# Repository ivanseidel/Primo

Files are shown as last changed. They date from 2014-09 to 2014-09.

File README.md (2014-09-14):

Custom Primo Version
=====

New here? Go to the [Manual](https://github.com/ivanseidel/Primo/blob/master/Manual.pdf?raw=true).

Or [Download all files](https://github.com/ivanseidel/Primo/archive/master.zip).

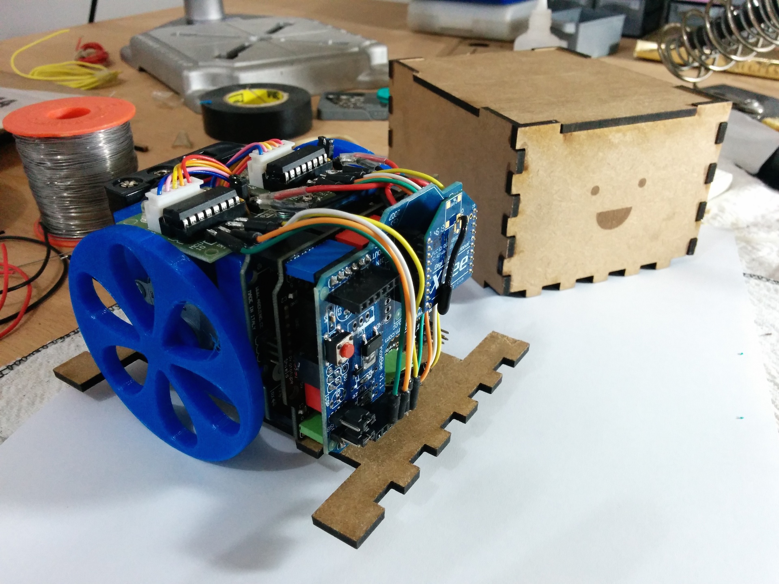
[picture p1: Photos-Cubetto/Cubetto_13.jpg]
Cubetto

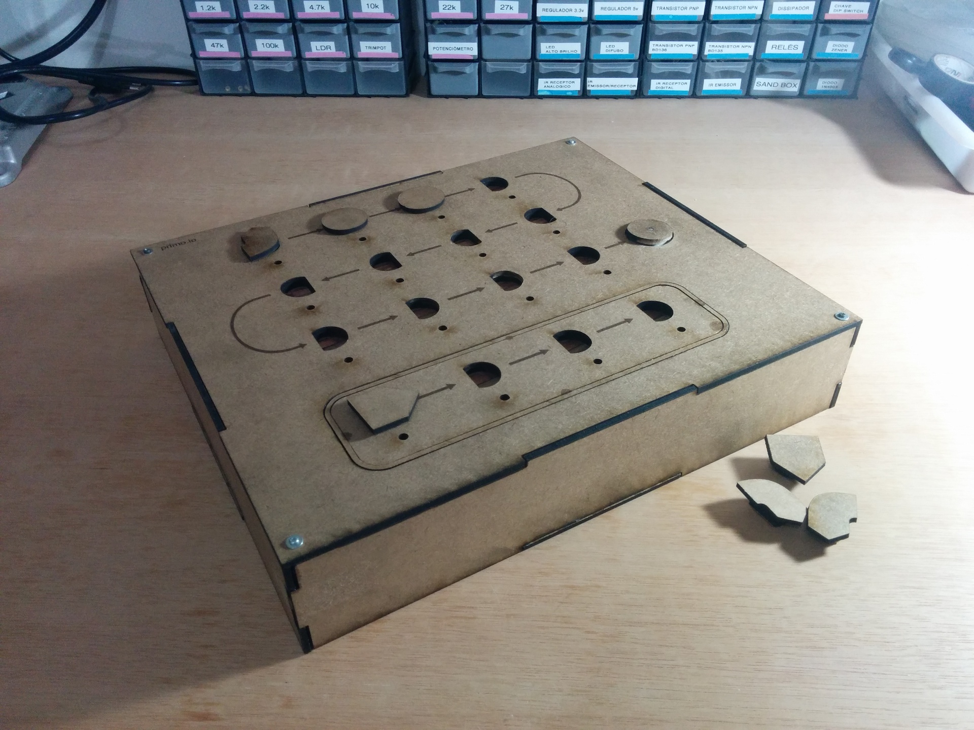
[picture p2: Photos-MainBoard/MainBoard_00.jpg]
Main Board


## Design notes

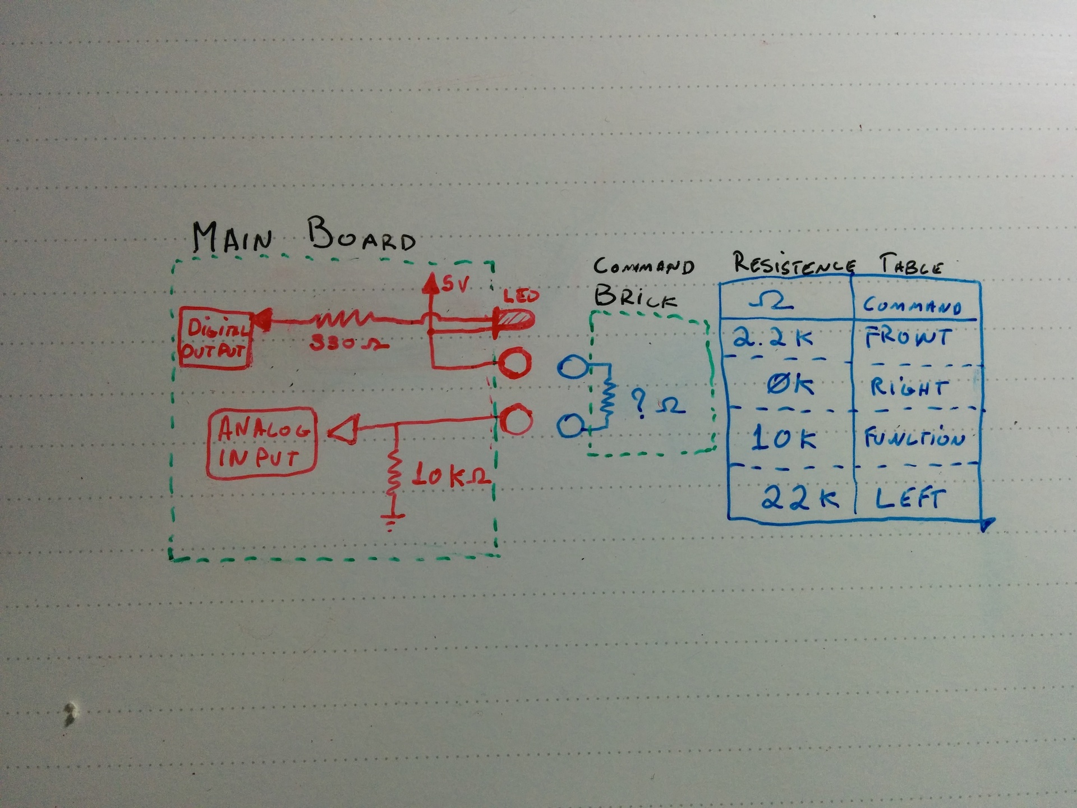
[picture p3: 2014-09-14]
Photos-MainBoard/Schematic_unit.jpg

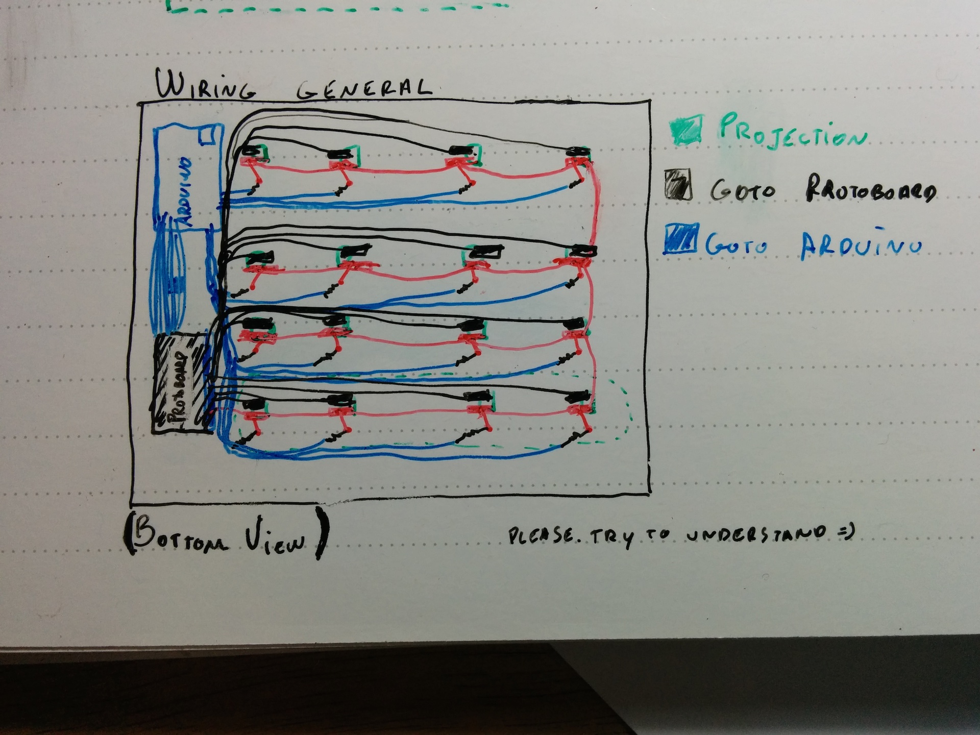
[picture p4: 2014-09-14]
Photos-MainBoard/Schematic_overview.jpg

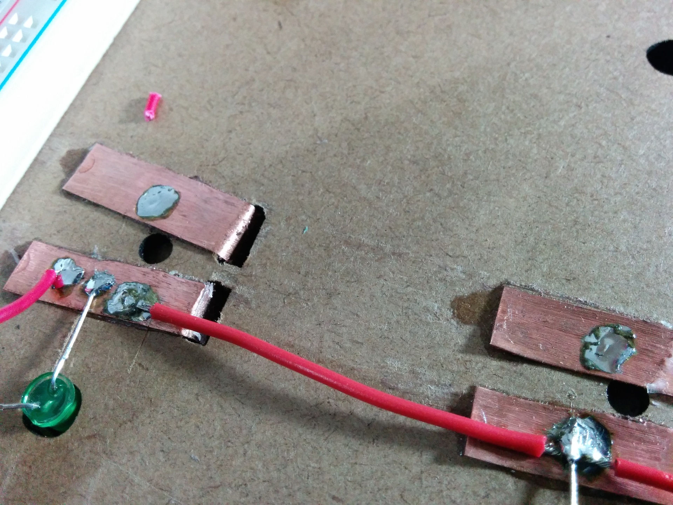
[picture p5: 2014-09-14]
Photos-MainBoard/MainBoard_10.jpg

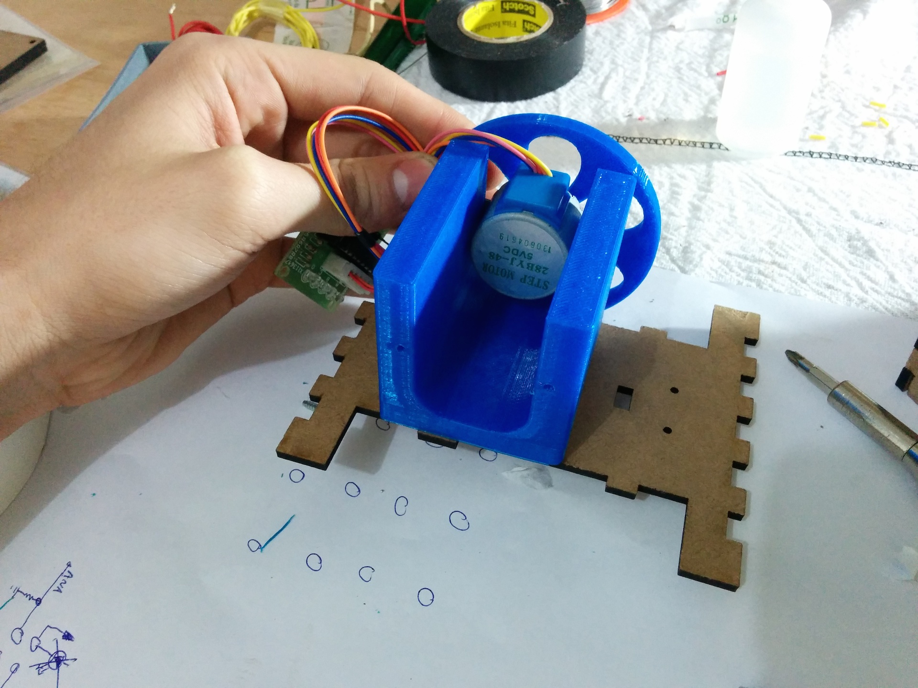
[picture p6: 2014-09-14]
Photos-Cubetto/Cubetto_01.jpg

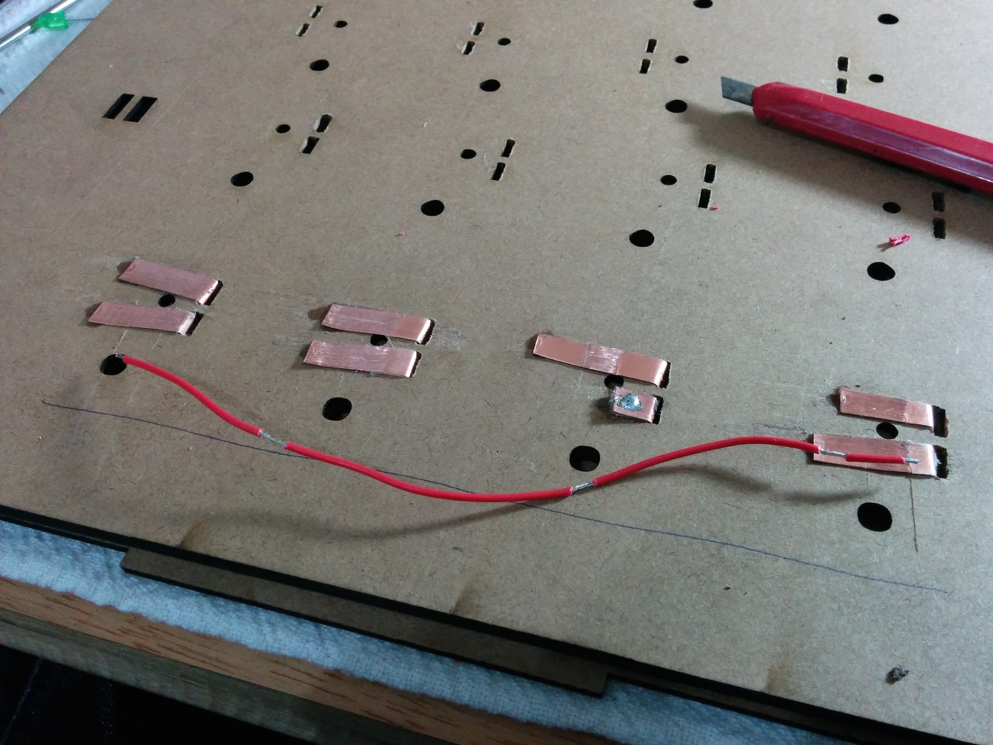
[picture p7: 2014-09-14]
Photos-MainBoard/MainBoard_07.jpg

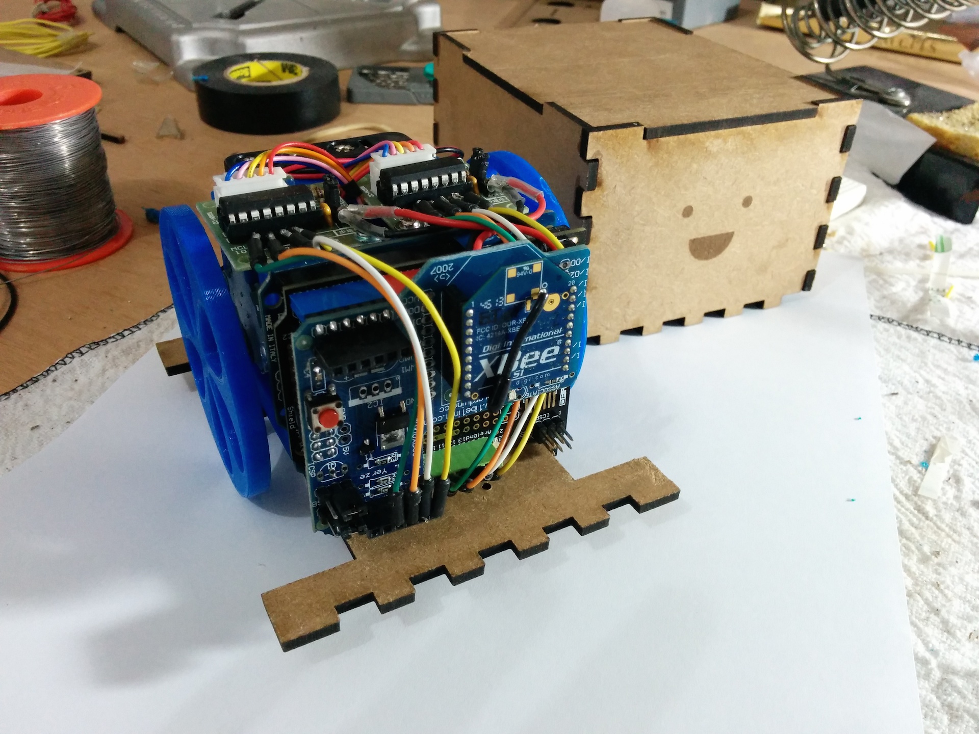
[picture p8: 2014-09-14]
Photos-Cubetto/Cubetto_12.jpg

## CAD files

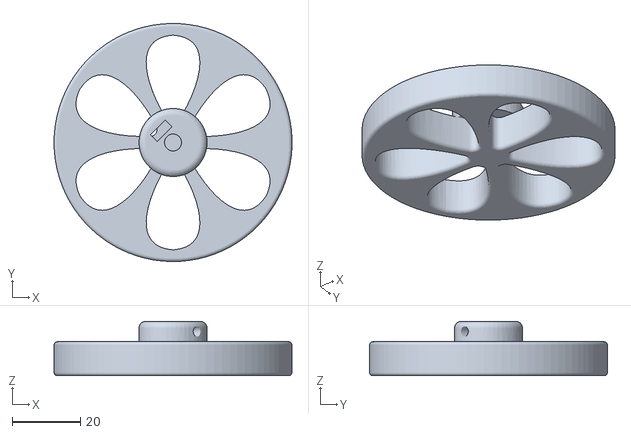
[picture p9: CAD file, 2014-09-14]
Mecanica/Whell.STL
70.0 x 70.0 x 16.0

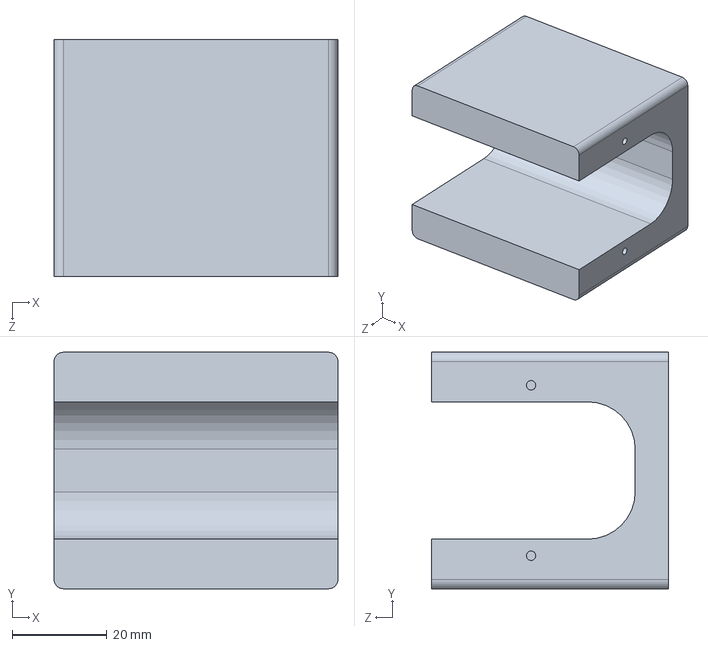
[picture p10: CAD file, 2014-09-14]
Mecanica/Suporte_motor_passo.SLDPRT
60.0 x 50.0 x 50.0 mm

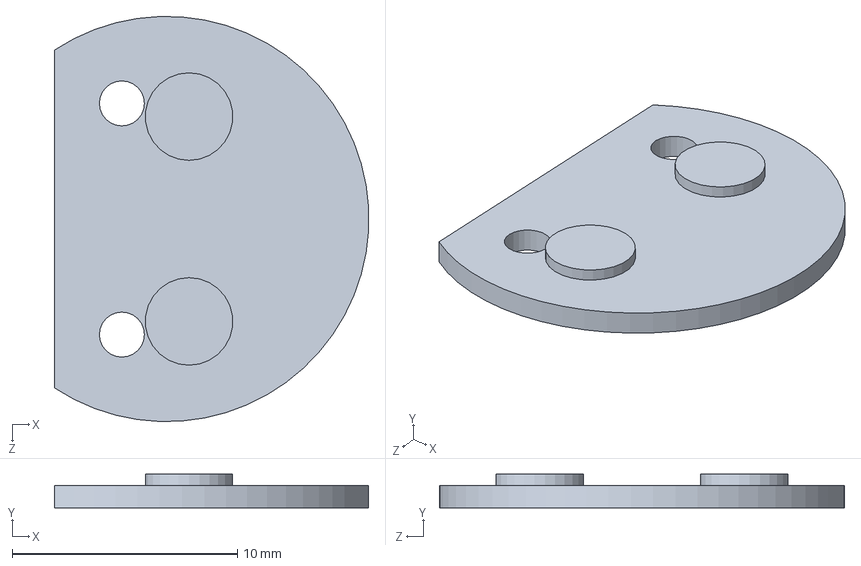
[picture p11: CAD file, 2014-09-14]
Mecanica/Block Base.SLDPRT
14.0 x 1.50 x 18.0 mm

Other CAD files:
Mecanica/Block Base.STL
Mecanica/Suporte_motor_passo.STL

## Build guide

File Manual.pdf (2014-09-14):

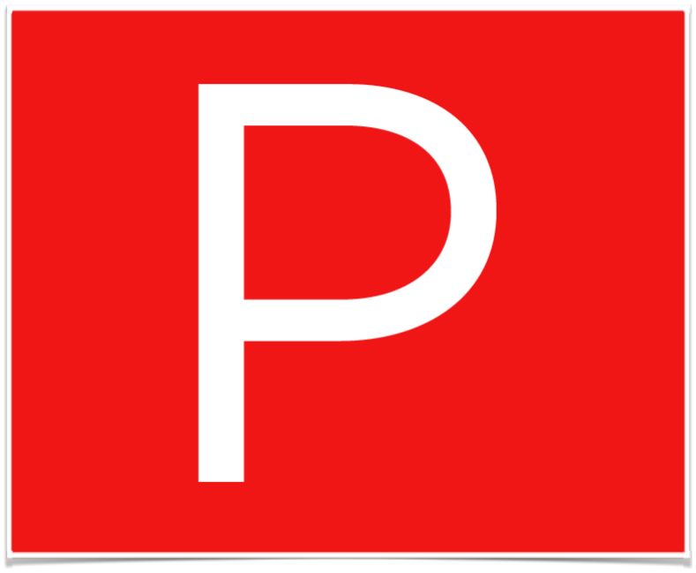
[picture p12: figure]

# Custom Primo Version

Ivan Seidel Gomes | ivanseidel@gmail.com
Repository: GitHub.com/ivanseidel/Primo
Company: SESI-SP - Brazil
September 13, 2014

Released into the public domain.

# INTRODUCTION

I work at SESI-SP (SESI São Paulo) in Brazil, and we wanted to spread the knowledge that Primo could provide to kids inside SESI Schools, at the same time that older kids could also learn-by-doing it.

Goals
The idea is to produce Primo for a large number of schools in the state of São Paulo, Brazil, because of that, we required a prototype version. This version aims to be a prototype of the next version, that will be more replicable and scalable.

Problem
Electronics parts in Brazil are really expensive (actually, everything imported). Also, some of them are not easily accessible in the market, meaning that would require import of parts and components.

Solution
Because of that, some of the parts were modified and even improved, so that the next version could be produced with a lower material cost, and be easily built by kids with the given material, just like a “Primo Kit”.

Project Outline
The prototype was mainly focused on putting it to work. Some of the solutions found could also help others on building it. A few major changes in the Prototype:
- Use of Stepper motors. They require less hardware (only an small H-bridge) without encoders, they are smaller, and also provide a precise control over (real) speed of wheels. One other great thing, is that if the motor are stucked (maybe a finger on the wheel?), they nicely stops running without hurting body parts.
- Use of 3D Printed parts for Cubetto. A few parts were designed to support motors, and also the wheels. But, they can be arranged to be Laser cutted as well.
- A hole new Software. With this new Software, it can easily setup, and even change Communication, add more Brick types, add more commands, add more function…
- Command Bricks were NOT build with Copper tape. Finding it in Brazil is hard, so the bricks were done using a small PCB with two contacts.
- Main board uses only a few Copper tape, and more wires (that will be replaced by a PCB board on the next version).
- Used only 4mm MDF boards. It’s difficult to find other than 4mm in Brazil, and it worked just great.

# CUBETTO

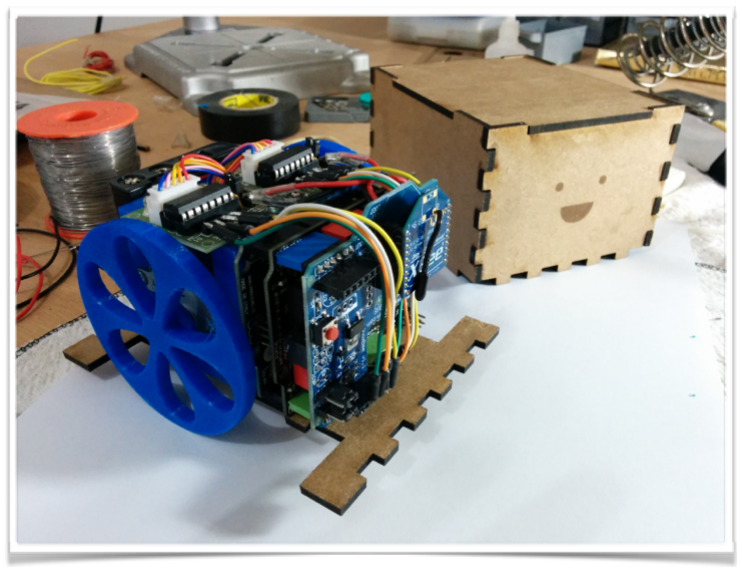
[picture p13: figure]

### BILL OF MATERIALS

Description | URL | Quantity | Unit Price | Cost
Arduino Shield - Prototipando | RoboCore (https://www.robocore.net/modules.php?name=GR_LojaVirtual&prod=339) | 1 | R$ | 59 | R$ | 59
Stepper Motor + H-Bridge | DealExtreme (http://www.dx.com/pt/p/28ybt-48-stepper-motor-with-uln2003-driver-dc-5v-126409#.VBTo6GTF-wM) | 2 | R$ | 10 | R$ | 20
Arduino UNO (or Leonardo) | Proesi (http://proesi.com.br/catalog/product/view/id/6152/s/arduino-leonardo-r3-cabo/) | 1 | R$ | 67 | R$ | 67
Arduino xBee Shield | Proesi (http://proesi.com.br/arduino-x-bee-shield.html) | 1 | R$ | 66 | R$ | 66
xBee Series 1 - 1mw | LabDeGaragem (http://www.labdegaragem.org/loja/xbee-1mw-wire-antenna.html) | 1 | R$ | 117 | R$ | 117
Esfera deslizante | RoboCore (https://www.robocore.net/modules.php?name=GR_LojaVirtual&prod=210) | 1 | R$ | 13 | R$ | 13
3D Printed Parts | | | | | R$ | 0
Jumpers, Dual face tape, Super glue… | | | | | R$ | 0
Total | | | | | R$ | 342

### BUILD FLOW (SIMPLE)

1. Print the Motor support in Mecanica/Suporte_motor_passo.STL
2. Print the wheels (or find one that fits the Stepper motor). It should have about 7cm of Diameter and 9mm of tickness (maximum). I used the wheel from another project of mine, that fitted just well. You need to resize it in tickness by about 50% (half of the height).
3. Glue the outside (Only the walls of Cubetto). Add some small pieces of [any-material-here] on the sides of the Walls (See picture Photos-Cubetto/Cubetto_08.jpg).
4. Place some double-sided tape on the base, and glue the Motor Support (it should be as shown on picture Photos-Cubetto/Cubetto_03.jpg. Leave enough space for your Battery behind it (measure it by adding the walls.
5. Put the ball roller on the bottom of Cubetto.
6. Attach the Arduino to the Prototype shield. Then Add the xBee Shield. Add some double-sided tape or even dual-lock on the side of the Motor Support, and add the Arduino there. See Photos-Cubetto/ Cubetto_07.jpg.
7. Add the H Bridges on top of the motor support. Either glue, add a screw… Fix it there as shown on Photos-Cubetto/Cubetto_03.jpg
8. Solder the + and - of each H Bridge to the Prototype bridge and it’s data pins as shown on Photos-Cubetto/Cubetto_11.jpg
9. Zip it all. See picture

### TIPS AND TRICKS

+ Do not glue the walls to the base. You will need to remove them all the time…

+ Do not glue the top as well. You might need to see inside, turn off/on, reset Arduino…

+ Make a role on the wheel, so that you can plug the cable to the Arduino. Since the wheels I designed already had some holes, I just had to “open” it a bit more.

+ If the stepper motors are not working really well… Well… Check the wiring order. They DO matter.

+ I started with 4 AAA. Then changed to 8 AAA. Then changed to a 9V battery. Result: 9V battery are not so good. 4 AAA either. Use 8 AAA or any kind of 2S Lipo/LiFe Battery of about 7.4v.

+ The height of my build was exceeding by about 1mm. It might be good to increase it a bit… But not a big worry for now.

# PRIMO MAIN BOARD

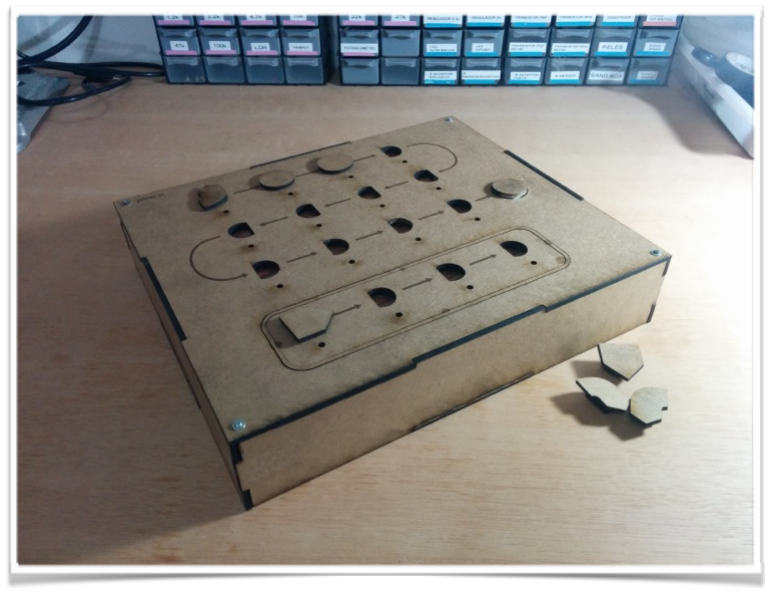
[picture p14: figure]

### BILL OF MATERIALS

Description | URL | Quantity | Unit Price | Cost
Electrical Wire Tape | Leroy Merlin (http://www.leroymerlin.com.br/eletrofita-para-iluminacao-21,5mm-15a-eletrofitas_87986094?origin=e83a5d030b071288e35b3bbe) | 1 | R$ | 28 | R$ | 28
or.. Cooper Tape | MercadoLivre (http://lista.mercadolivre.com.br/fita-cobre) | 2 | R$ | 15 | R$ | 30
Arduino Mega | Proesi (http://proesi.com.br/arduino-mega-2560-acompanha-cabo-usb.html) | 1 | R$ | 99 | R$ | 99
Arduino xBee Shield | Proesi (http://proesi.com.br/arduino-x-bee-shield.html) | 1 | R$ | 66 | R$ | 66
xBee Series 1 - 1mw | LabDeGaragem (http://www.labdegaragem.org/loja/xbee-1mw-wire-antenna.html) | 1 | R$ | 117 | R$ | 117
Small Protoboard (100 dots) | Proesi (http://proesi.com.br/catalog/product/view/id/6977/s/protoboard-sem-base-100-pontos/) | 1 | R$ | 15 | R$ | 15
Screws, nuts… | | | | | R$ | 0
Jumpers, Dual face tape, Super glue… | | | | | R$ | 0
Total | | | | | R$ | 355

### BUILD FLOW (SIMPLE)

1. You will only need 4 MDF Boards for the top. One for the bottom, and one for each side (find them). They will be grouped into two groups:
1. The exterior with two layers. Top one with the drawing (arrows…), and bottom one with the block holes. See photo Photos-MainBoard/MainBoard_01.jpg.
2. The Hardware layer. Here is were the fun (mess) will be. All electronics will be placed here, including Arduinos, Protoboards, wires… See Photos-MainBoard/MainBoard_03.jpg.
2. Add double-sided tape in the middle of each layer from above. NOTE: DO NOT GLUE BOTH GROUPS. See Photos-MainBoard/MainBoard_21.jpg. The two layers from top, are separated from the Bottom with a Screw nut. That’s because the Cooper Tape will add a height to that layer.
3. Glue the walls. Same tips as the Cubetto. Add some reinforcements to the edge.
4. If you are using Cooper Tape: GREAT. Just cut it in parts of about 5cm. You might need to ‘increase' the hole to fit. See Photos-MainBoard/MainBoard_05.jpg and Photos-MainBoard/MainBoard_06.jpg.
5. Place the Arduino and the Protoboard as shown on Photos-MainBoard/MainBoard_09.jpg. It’s a good place to place it.
6. Because I don’t like Cooper tape pretty much, I used wires. This is a major point, where will be simplified with multiple PCB boards for Command Brick contacts. I made some small changes to the Schematic of connection. Here is how each Block Terminal is wired and the big picture:

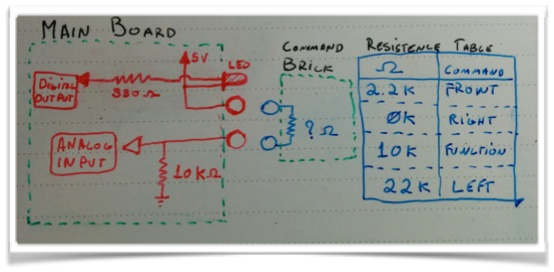
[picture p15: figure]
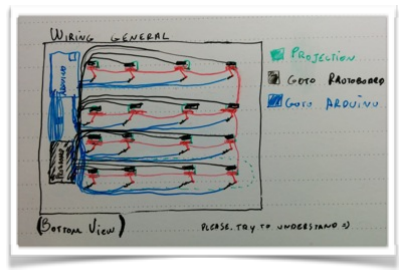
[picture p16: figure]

7. Solder All Positive wires, the Red ones in the photo: Photos-MainBoard/MainBoard_14.jpg. (NOTE: They will go to the Breadboard. You can group them all together…)
8. Solder the POSITIVE terminal of all the Led’s to the Positive terminal of the Command Brick contact. See Photos-MainBoard/MainBoard_11.jpg. (NOTE: The side of the Command Brick terminal doesn’t matter, but since there is an LED on the side, try setting the closest side as the Positive, otherwise, you will have some trouble soldering the LED’s to the terminal pads).
9. Solder a resistor (330Ω) to the led’s NEGATIVE terminal. Then solder an Jumper and wire it to the Arduino (it doesn’t need to go to the Breadboard). See Photos-MainBoard/MainBoard_15.jpg and Photos-MainBoard/MainBoard_16.jpg.

10. Solder all Command Brick signal contacts, the Yellow ones in the photo: Photos-MainBoard/ MainBoard_14.jpg. (NOTE: They will also go to the Breadboard).
11. Hook each yellow wire to the Breadboard (place them in order, please…), and add at each one, a 10KΩ Resistor. See Photos-MainBoard/MainBoard_18.jpg.
12. Now it becomes a (inevitable) mess. Hook each yellow brick terminal to the proper Analog Input pin on the Arduino with some Jumpers. See mess in Photos-MainBoard/MainBoard_19.jpg. You can configure it really easy. Go to PrimoConfig.h in Softwares/Primo_Board. You can change
any pin you want. Note that they are in order, and grouped into
MainProgram and FunctionProgram, that are the Normal Flow
(MainProgram) and the Function Flow (FunctionProgram).

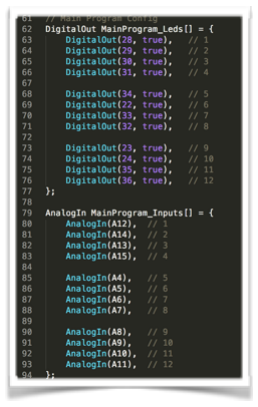
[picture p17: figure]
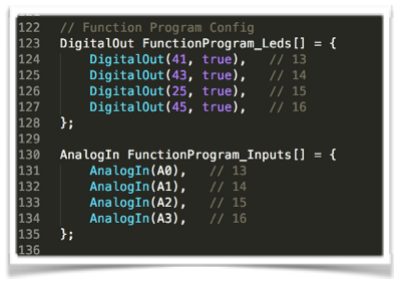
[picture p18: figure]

13. Next, you should really tight things up. Use something to make things look not-so-crazy.
14. Invent your button. I used this push button: Photos-MainBoard/MainBoard_23.jpg, hot glued it on the hole, and super-glued it to the button cover, then soldered it and hooked it to the GND, and a Digital pin. (NOTE: The pin is being Pulled-Up in software, so you MUST set the other side to GND, not 5v).
15. Workaround for xBee. Arduino Mega has many Serial ports. And both xBee and USB were creating lot’s of problems. So, I decided to Hack things a little bit more, and changed the Serial pin from the Shield to the Serial1 from the Arduino (RX1 and TX1). See Photos-MainBoard/MainBoard_25.jpg. I have jumped the Serial TX and RX to TX1 and RX1.

# COMMAND BRICKS

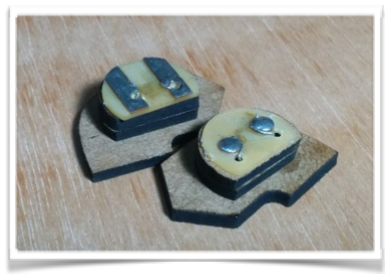
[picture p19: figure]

I guess that the only change in here, was that I made a small PCB to serve as the bottom pad. However, you can use the original Primo Brick instructions, they will work just well if you have the appropriate Copper Tape.

For the Bricks, I have used the following resistors with a 10K Pull-Down Resistor (added to the Breadboard):

- RIGHT: 0Ω (Just a wire jumper)
- FRONT: 2.2KΩ
- FUNCTION: 10KΩ
- LEFT: 22KΩ

If you need, you can change the resistors as well. To do so, make sure that the ADC value will vary at least 60 units from one another.

Take R2 as the Pull-Down Resistor (in my case, 10KΩ), and V as the Voltage (in the general case, 5v)

The ADC read by the Arduino, will be:
ADC = (V*R2 / (R2 + YourResistance)) / V * 1023

Then go to PrimoConfigs.h inside Software/Primo_Board and alter the corresponding line value in the BLOCK_STATES[]:

Thats it.

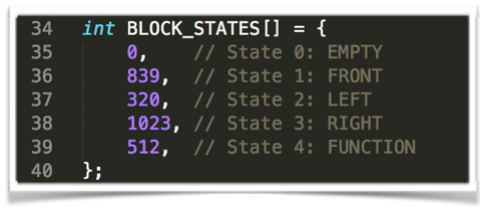
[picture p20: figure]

# SOFTWARE

There are two main programs inside the Software folder:

- Primo_Cubetto: Controls the Cubbeto by listening to the Serial and doing commands.
- Primo_Board: Controls the Board, flashes light, Compile, Generate commands, and execute them by sending it over Serial interface.

### DEPENDENCIES

I used a few libraries to make the code Reliable, Generic, and easy to change if anyone needs it. It is based on my other Library called ArduinoThreads (http://GitHub.com/ivanseidel/ArduinoThread).

Also, it makes use of ArduinoSensors (http://GitHub.com/ivanseidel/ArduinoSensors) to read from IO, and debounce sensors.

As well as LinkedList (http://GitHub.com/ivanseidel/LinkedList), so that the program can be compiled into a generic PrimoProgram, and latter be sent over Serial.

And for Cubetto, I used AccelStepper (http://www.airspayce.com/mikem/arduino/AccelStepper/) to control the Stepper motor.

Make sure to have them installed.

It might look like a lot of things for get this going, but the goal is do do even more complex things with time, including: If’s, Whiles, Wait blocks (Wait for Sound, Wait for touch…).

### GET THINGS GOING

1. First, download those Dependencies (ArduinoThreads, ArduinoSensors, LinkedList), install them (copy to the Libraries folder of the Arduino), and Restart the Arduino Software.
2. Load the Primo_Cubetto, and upload to Cubetto.
3. Load the Primo_Board, and upload to the Board.
4. One extra step, is configure the xBee. If you xBee is not configured yet, read this: https://learn.sparkfun.com/tutorials/exploring-xbees-and-xctu
5. All ok =)

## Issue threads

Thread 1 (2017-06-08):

Vector file for laser cutting the main-board and the Cubetto outside

ghiet, 2017-06-08:
Would it be possible to include the vector file of the main-board and the Cubetto outside to laser cut them?

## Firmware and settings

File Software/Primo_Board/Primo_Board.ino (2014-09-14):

/*
 	Controls Primo Board

	For instructions, go to https://github.com/ivanseidel/Primo

	Created by Ivan Seidel Gomes, September, 2014.
	Released into the public domain.

	Dependencies
	I used a few libraries to make the code Reliable, Generic,
	and easy to change if anyone needs it.

	It is based on my other Library called ArduinoThreads
	(http://GitHub.com/ivanseidel/ArduinoThread).

	Also, it makes use of ArduinoSensors
	(http://GitHub.com/ivanseidel/ArduinoSensors) to read
	from IO, and debounce sensors.

	As well as LinkedList (http://GitHub.com/ivanseidel/LinkedList),
	so that the program can be compiled into a generic PrimoProgram,
	and latter be sent over Serial. 

	Make sure to have them installed.
	
	It might look like a lot of things for get this going, but the
	goal is do do even more complex things with time, including: If’s,
	Whiles, Wait blocks (Wait for Sound, Wait for touch…).

	Have fun =)
*/

// Third-Party Libraries
#include <ArduinoThread.h>
#include <ThreadController.h>

#include <ArduinoSensors.h>
#include <DigitalOut.h>
#include <AnalogIn.h>

#include <LinkedList.h>

// Primo stuff
#include "Block.h"
#include "Button.h"
#include "PrimoConfigs.h"

#include "PrimoCompiler.h"
#include "PrimoExecuter.h"

// Function LED's (Program)
#define PR 1
#define FN 13

// CPU
ThreadController CPU;

ThreadController MainProgramController;
ThreadController FunctionProgramController;

// Initialize Primo Classes
PrimoCompiler *compiler;
PrimoProgram *rootProgram;
PrimoExecuter *primoExecuter;


/*
	This Callback Function will be called
	everytime the user Presses the button
	on the Board.

	It will Compile and Execute Primo Tasks,
	or if it's already running, will stop it first.
*/
void onUserPressedStart(){

	// If is running, force stop then re-start
	if(primoExecuter->getState() == RUNNING){
		Serial.println("Stopping...");
		primoExecuter->stop();
	}

	Serial.print("Compiling...");

	compiler->Compile(rootProgram);

	Serial.print(rootProgram->size());
	Serial.print(" [ ");
	for(int i = 0; i < rootProgram->size(); i++){
		Serial.print(rootProgram->get(i)->command);
		Serial.print(' ');
	}
	Serial.println("]");

	// Start Primo Executer
	primoExecuter->start();
}

/*
	Called when PrimoExecuter wants to send a command
*/

void sendCommandViaRadio(char command){

	Serial1.write(command);

	Serial.print("SENT COMMAND: ");	
	Serial.println(command);
}

Thread test;
void thrTest(){
	// Serial1.println("Hey!");
	// Serial.println("alive");
	while(Serial1.available())
		Serial.println(Serial1.read(), HEX);
	while(Serial.available())
		Serial1.write(Serial.read());
}

/*
	This is where mostly part of the program is
	tighten toguether.

	I'm using Calbacks, and multiple Threads to do
	the work of keeping track of each block inserted,
	When the button is pressed, and even the Program
	Execution is done in parallel with other Tasks;

	Because of that, we inject into the ThreadController
	CPU all the Threads and ThreadController groups that
	we want keep running and leave the CPU.run() in the
	main loop to do it's work
*/
void setup() {
	// Initialize Serial Ports
	Serial.begin(9600);
	Serial1.begin(9600);
	while(!Serial && !Serial1);
	Serial.println("\nPRIMO v1.0\n");

	// Initialize MainProgram Blocks
	for(int b = 0; b < MainProgram_SIZE; b++){
		MainProgram[b] = new Block(
			// ID of this Block
			b,
			// AnalogIn object
			&MainProgram_Inputs[b],
			// DigitalOut object
			&MainProgram_Leds[b],
			// Possible STATES
			BLOCK_STATES,
			// Number of states
			nBLOCK_STATES);

		// Add the Block to the Thread List
		MainProgramController.add(MainProgram[b]);
	}

	// Initialize FunctionProgram Blocks
	for(int b = 0; b < FunctionProgram_SIZE; b++){
		FunctionProgram[b] = new Block(
			b,
			&FunctionProgram_Inputs[b],
			&FunctionProgram_Leds[b],
			BLOCK_STATES,
			// Function state is the last. We remove it to avoid recursivity
			nBLOCK_STATES);

		// Add the Block to the Thread List
		FunctionProgramController.add(FunctionProgram[b]);
	}

	// Add both Main and Function Controllers to CPU
	MainProgramController.setInterval(100);
	CPU.add(&MainProgramController);

	FunctionProgramController.setInterval(100);
	CPU.add(&FunctionProgramController);

	// Initialize Start Button listner and add to CPU
	StartButton.onBump = onUserPressedStart;
	CPU.add(&StartButton);

	// This is our Program. Initializing it...
	rootProgram = new PrimoProgram();
	
	// Copiler is who does the hard working on creating our program
	compiler = new PrimoCompiler(
		MainProgram, MainProgram_SIZE,
		FunctionProgram, FunctionProgram_SIZE);

	// Executer is who executes a program
	primoExecuter = new PrimoExecuter(rootProgram);
	// Set delegator for sending messages
	primoExecuter->executeCommand = sendCommandViaRadio;
	// Add to CPU
	CPU.add(primoExecuter);


	// Test thread
	test.setInterval(500);
	test.onRun(thrTest);
	CPU.add(&test);

}

void loop() {
	CPU.run();
}

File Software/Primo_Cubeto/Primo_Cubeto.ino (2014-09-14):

/*
 	Controls Cubetto

	For instructions, go to https://github.com/ivanseidel/Primo

	Created by Ivan Seidel Gomes, September, 2014.
	Released into the public domain.

	Dependencies
	I used a few libraries to make the code Reliable, Generic,
	and easy to change if anyone needs it.

	It is based on my other Library called ArduinoThreads
	(http://GitHub.com/ivanseidel/ArduinoThread).

	I also used AccelStepper
	(http://www.airspayce.com/mikem/arduino/AccelStepper/)
	to control the Stepper motor.

	Make sure to have them installed.
	
	It might look like a lot of things for get this going, but the
	goal is do do even more complex things with time, including: If’s,
	Whiles, Wait blocks (Wait for Sound, Wait for touch…).

	Have fun =)
*/

#include <ArduinoThread.h>
#include <ThreadController.h>

#include <AccelStepper.h>

// Motores de Passo
AccelStepper Left(AccelStepper::HALF4WIRE, 9, 10, 11, 12);
AccelStepper Right(AccelStepper::HALF4WIRE, 4, 5, 6, 7);

// CPU
ThreadController CPU;

// Thread to Execute Motor commands
Thread MotorThread;
void thrRunMotors(){
	Left.run();
	Right.run();
}

// Power Saver Thread (disables outputs when idle)
Thread PowerSaver;
void thrPowerSaver(){
	// Release motors if idle
	if(Right.distanceToGo() == 0 && Left.distanceToGo() == 0){
		Left.disableOutputs();
		Right.disableOutputs();
	}
}

// Read command and execute (executes in parallel)
Thread CommandReader;
void thrCommandReader(){
	int cmd = 0;

	if(!Serial1.available())
		return;

	// Enable Outputs
	Left.enableOutputs();
	Right.enableOutputs();

	cmd = Serial1.read();

	// Invert led state
	digitalWrite(13, !digitalRead(13));

	if(cmd == 1){
		// FRONT
	    Right.move(5000);
	    Left.move(5000);
	}else if(cmd == 2){
		// LEFT
		Right.move(1000);
	    Left.move(-1000);
	}else if(cmd == 3){
		// RIGHT
		Right.move(-1000);
	    Left.move(1000);
	}
}

void setup() {
	Serial.begin(9600);
	Serial1.begin(9600);

	// Configure Both Motors
    Right.setMaxSpeed(2200);
    Right.setAcceleration(3500);

	Left.setMaxSpeed(2200);
	Left.setAcceleration(3500);
    
	// Setup CPU
	MotorThread.onRun(thrRunMotors);
	MotorThread.setInterval(0);

	CommandReader.onRun(thrCommandReader);
	CommandReader.setInterval(500);

	PowerSaver.onRun(thrPowerSaver);
	PowerSaver.setInterval(1000);

	CPU.add(&MotorThread);
	CPU.add(&CommandReader);
	CPU.add(&PowerSaver);

	pinMode(13, OUTPUT);
}

void loop() {
	CPU.run();
}
